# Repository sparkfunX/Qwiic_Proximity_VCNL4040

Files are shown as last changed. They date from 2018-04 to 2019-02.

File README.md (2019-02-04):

SparkFun VCNL4040 Proximity Sensor (Qwiic) - VCNL4040
===========================================================

SparkFun Proximity Sensor (Qwiic) - VCNL4040

[*SparkX Proximity Sensor (Qwiic) - VCNL4040 (SPX-14690)*](https://www.sparkfun.com/products/14690)

The VCNL4040 is a simple IR presence and ambient light sensor. This sensor is excellent for detecting if something has appeared in front of the sensor. We often see this type of sensor on automatic towel dispensers, automatic faucets, etc. You can detect objects qualitatively up to 20cm away. This means you can detect if something is there, and if it is closer or further away since the last reading, but it's difficult to say it is 7.2cm away. If you need quantitative distance readings (for example sensing that an object is 177mm away) check out the [SparkFun Time of Flight (ToF) sensors](https://www.sparkfun.com/categories/84) with mm accuracy.

SparkFun labored with love to create this code. Feel like supporting open source hardware? 
Buy a [breakout board](https://www.sparkfun.com/products/14690) from SparkFun!

Repository Contents
-------------------

* **/Documents** - Datasheets
* **/Hardware** - Eagle design files (.brd, .sch)

Library
--------------
* **[Arduino Library](https://github.com/sparkfun/SparkFun_VCNL4040_Arduino_Library)** - Library for reading distance and configuring the sensor

License Information
-------------------

This product is _**open source**_! 

If you have any questions or concerns on licensing, please contact techsupport@sparkfun.com.

Please use, reuse, and modify these files as you see fit. Please maintain attribution to SparkFun Electronics and release any derivative under the same license.

Distributed as-is; no warranty is given.

- Your friends at SparkFun.

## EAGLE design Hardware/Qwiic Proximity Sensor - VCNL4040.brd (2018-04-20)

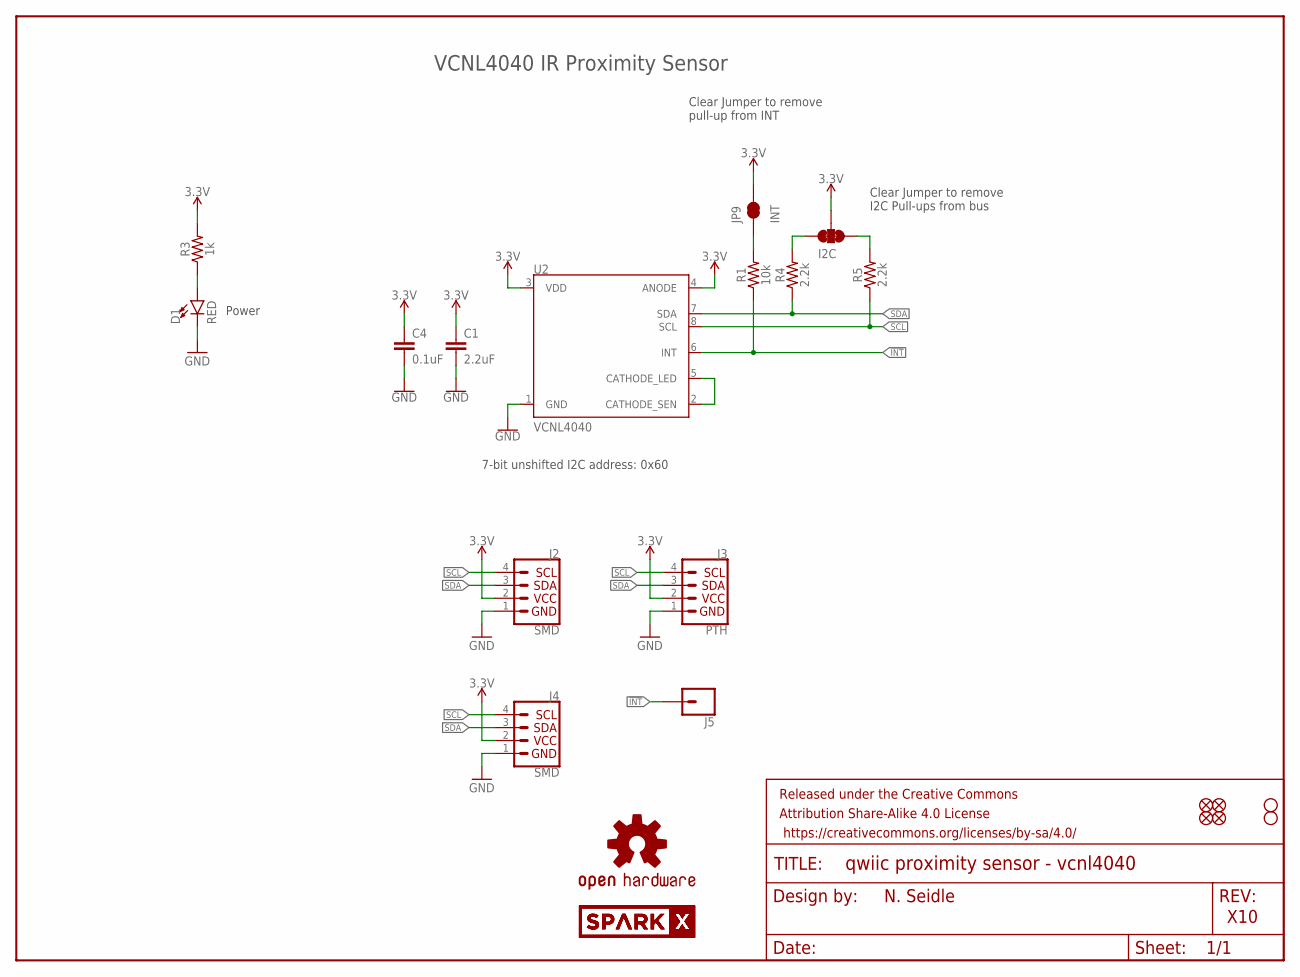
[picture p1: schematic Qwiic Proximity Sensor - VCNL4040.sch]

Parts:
C1: 2.2uF; 0603
C4: 0.1uF; 0603
D1: RED; LED-0603
FRAME1: FRAME-LETTER; CREATIVE_COMMONS
I2C: JUMPER-SMT_3_2-NC_TRACE_SILK; SMT-JUMPER_3_2-NC_TRACE_SILK
J2, J4: SMD; 1X04_1MM_RA
J3: PTH; 1X04_NO_SILK
J5: CONN_01PTH_NO_SILK_YES_STOP; 1X01_NO_SILK
JP1, JP2, JP5, JP6: FIDUCIALUFIDUCIAL; MICRO-FIDUCIAL
JP3, JP4: STAND-OFF
JP9: INT; PAD-JUMPER-2-NC_BY_TRACE_YES_SILK
LOGO1: OSHW-LOGOMINI; OSHW-LOGO-MINI
R1: 10k; 0603
R3: 1k; 0603
R4, R5: 2.2k; 0603
U2: VCNL4040
U$1, U$2: SPARKX-LOGO4; SPARKX-MEDIUM

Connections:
3.3V: C1.1, C4.1, I2C.2, J2.2 (VCC), J3.2 (VCC), J4.2 (VCC), JP9.2, R3.2, U2.3 (VDD), U2.4 (ANODE)
!INT: J5.1, R1.1, U2.6 (INT)
GND: C1.2, C4.2, D1.C, J2.1 (GND), J3.1 (GND), J4.1 (GND), U2.1 (GND)
unnamed: I2C.1, R5.2
unnamed: I2C.3, R4.2
unnamed: D1.A, R3.1
unnamed: JP9.1, R1.2
unnamed: U2.2 (CATHODE_SEN), U2.5 (CATHODE_LED)
SCL: J2.4 (SCL), J3.4 (SCL), J4.4 (SCL), R5.1, U2.8 (SCL)
SDA: J2.3 (SDA), J3.3 (SDA), J4.3 (SDA), R4.1, U2.7 (SDA)

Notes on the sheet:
N. Seidle
X10
7-bit unshifted I2C address: 0x60
Clear Jumper to remove I2C Pull-ups from bus
Clear Jumper to remove pull-up from INT
Power
VCNL4040 IR Proximity Sensor

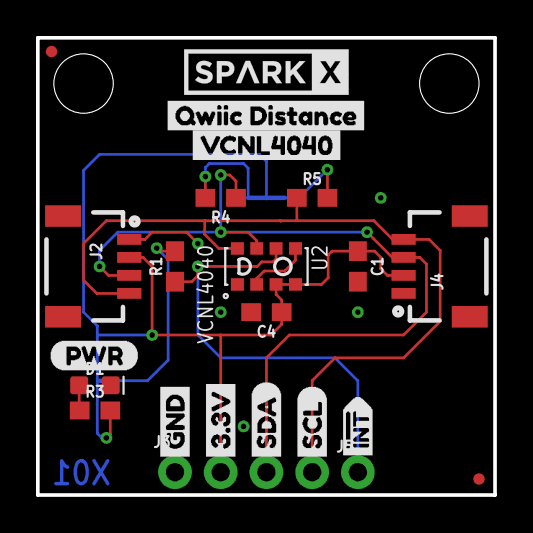
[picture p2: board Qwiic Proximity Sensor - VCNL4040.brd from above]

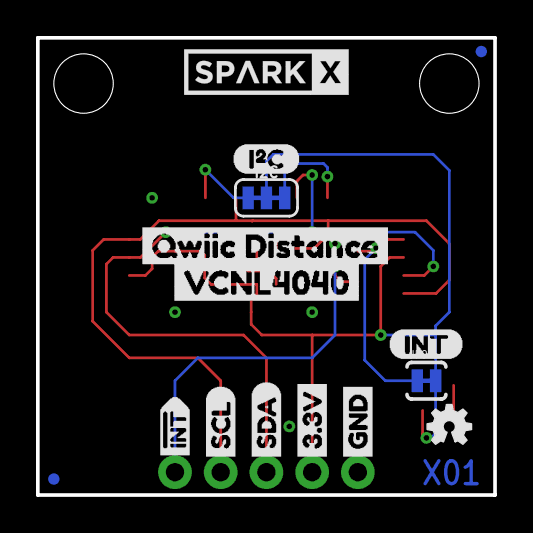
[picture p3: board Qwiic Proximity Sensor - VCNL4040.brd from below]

Board: 2 copper layers, 25.4 x 25.4 mm, 41 parts (15 on the bottom side), 10 nets.

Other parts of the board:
U$3, U$22: GND1
U$4, U$21: 3#3V2
U$5, U$27: SDA8
U$6, U$26: SCL9
U$7, U$25: #INT14
U$10: (PWR)
U$11: (I_SUPER2_C)
U$12: (INT)
U$13: VCNL40400
U$14: VCNL40401
U$15: QWIIC_DISTANCE7
U$19: QWIIC_DISTANCE9

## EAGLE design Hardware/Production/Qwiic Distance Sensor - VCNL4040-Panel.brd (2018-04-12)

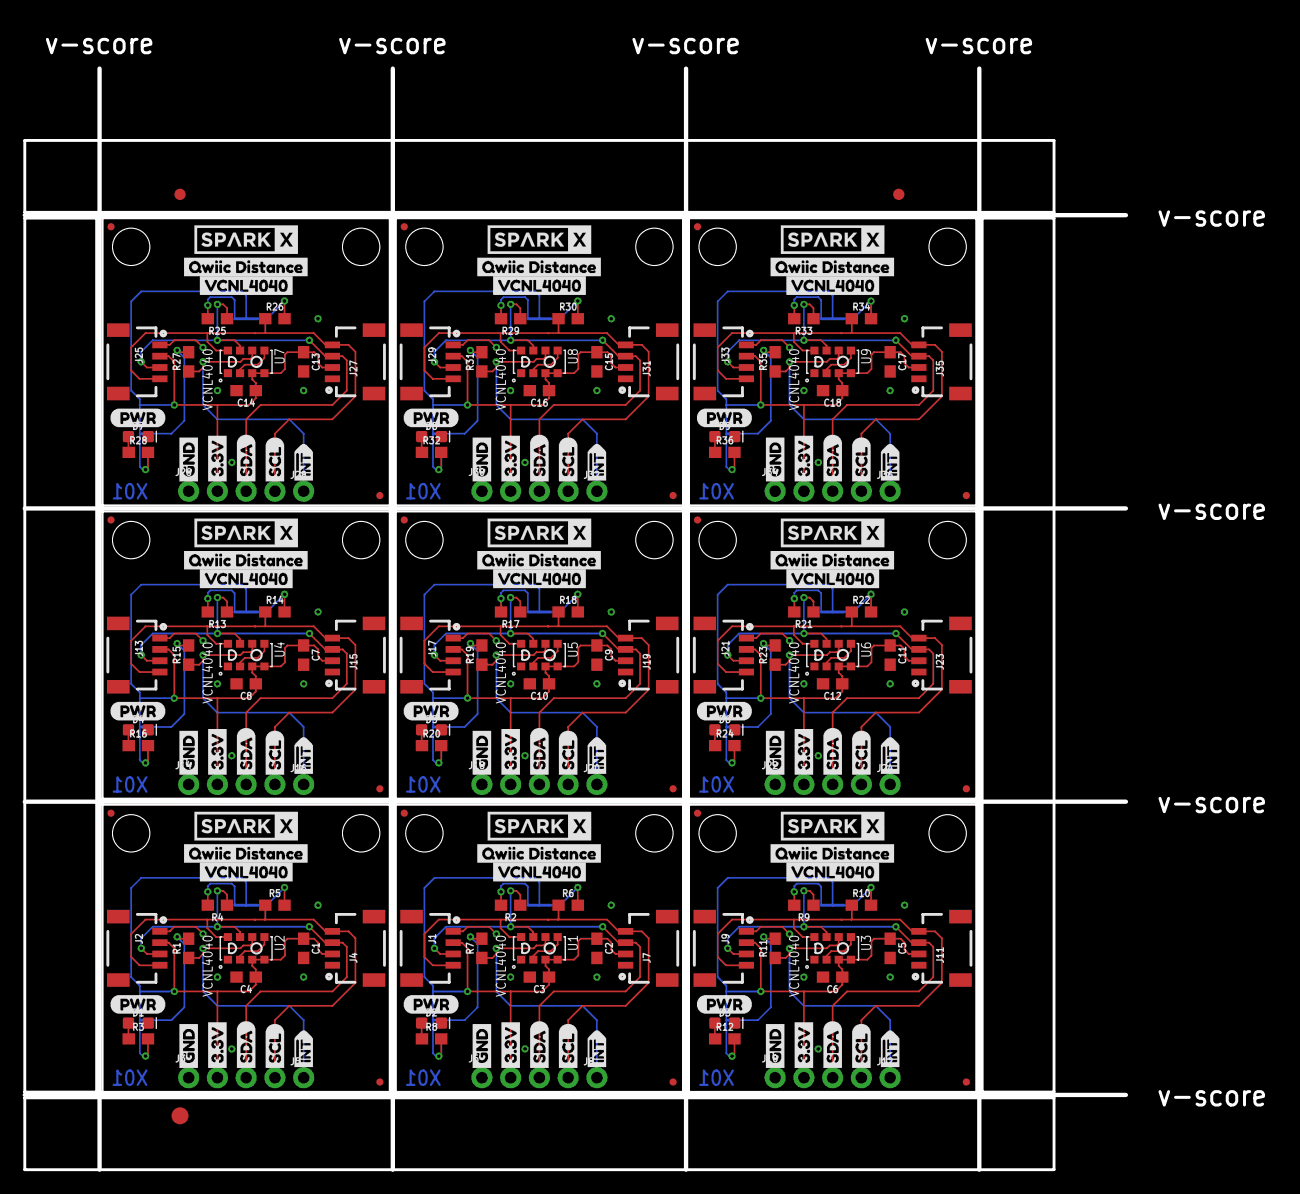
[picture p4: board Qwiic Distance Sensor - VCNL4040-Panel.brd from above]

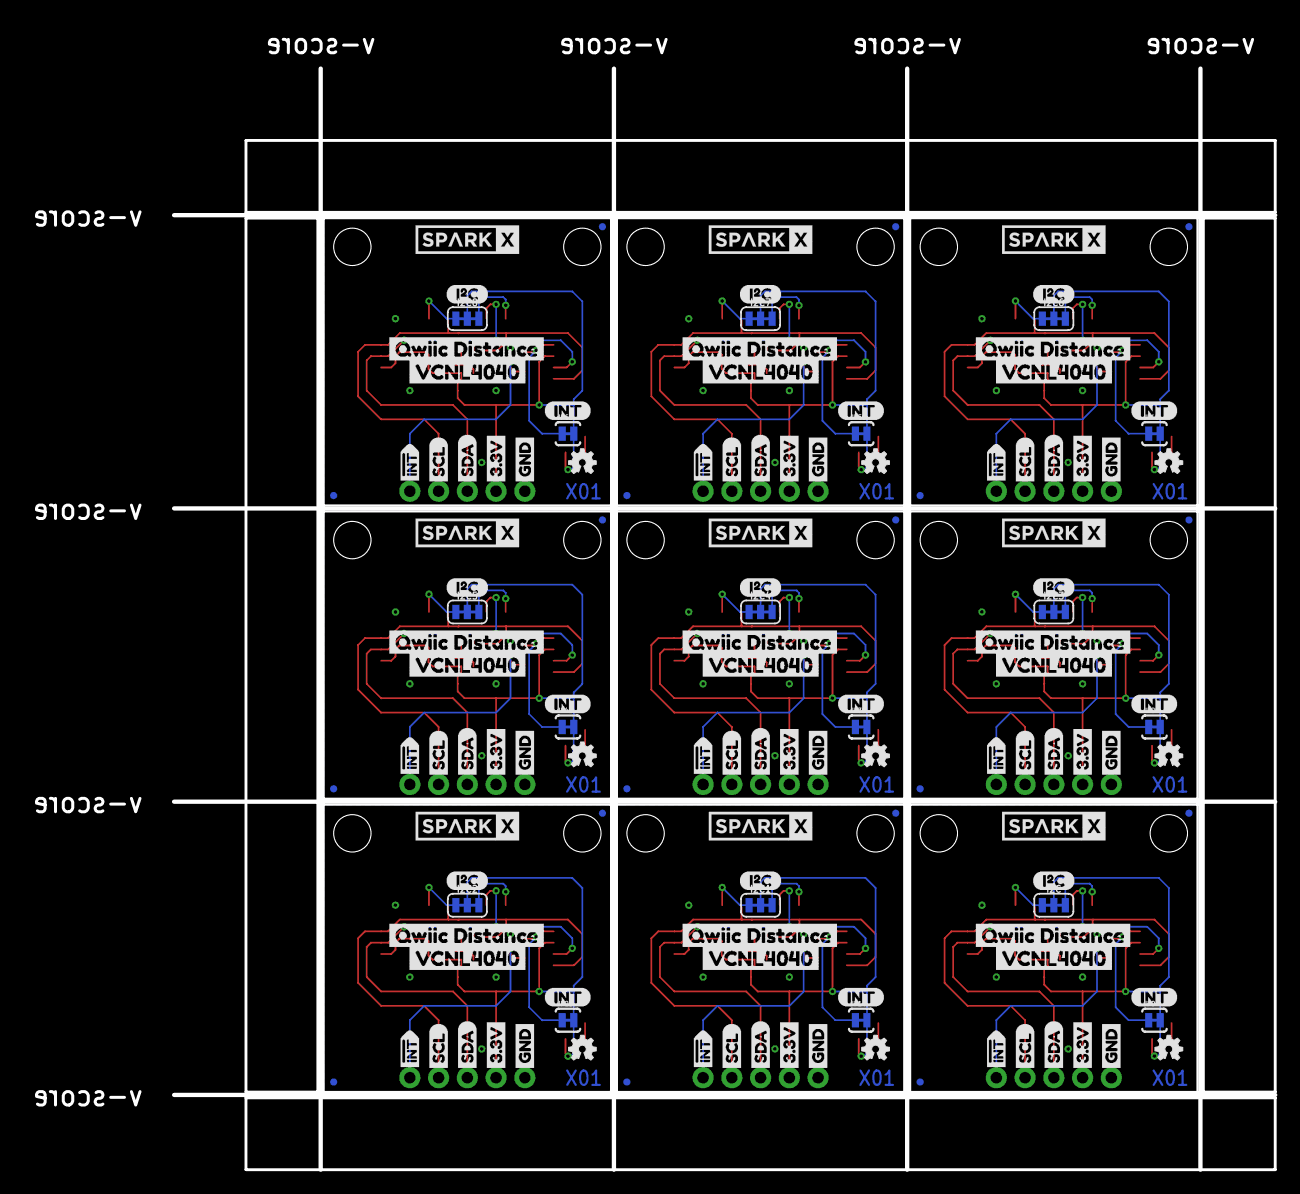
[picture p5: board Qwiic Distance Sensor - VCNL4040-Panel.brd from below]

Board: 2 copper layers, 97.3 x 97.3 mm, 363 parts (135 on the bottom side), 90 nets.

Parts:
C1, C2, C5, C7, C9, C11, C13, C15, C17: 2.2uF; 0603
C3, C4, C6, C8, C10, C12, C14, C16, C18: 0.1uF; 0603
D1, D2, D3, D4, D5, D6, D7, D8, D9: RED; LED-0603
E$1, E$2: FIDUCIAL-1X2
E$3: FIDUCIAL-1.5X3
I2C, I2C1, I2C2, I2C3, I2C4, I2C5, I2C6, I2C7, I2C8: SMT-JUMPER_3_2-NC_TRACE_SILK
J1, J2, J4, J7, J9, J11, J13, J15, J17, J19, J21, J23, J25, J27, J29, J31, J33, J35: SMD; 1X04_1MM_RA
J3, J6, J10, J14, J18, J22, J26, J30, J34: PTH; 1X04_NO_SILK
J5, J8, J12, J16, J20, J24, J28, J32, J36: 1X01_NO_SILK
JP1, JP2, JP5, JP6, JP10, JP11, JP12, JP13, JP17, JP18, JP19, JP20, JP24, JP25, JP26, JP27, JP31, JP32, JP33, JP34, JP38, JP39, JP40, JP41, JP45, JP46, JP47, JP48, JP52, JP53, JP54, JP55, JP59, JP60, JP61, JP62: FIDUCIALUFIDUCIAL; MICRO-FIDUCIAL
JP3, JP4, JP7, JP8, JP15, JP16, JP22, JP23, JP29, JP30, JP36, JP37, JP43, JP44, JP50, JP51, JP57, JP58: STAND-OFF
JP9, JP14, JP21, JP28, JP35, JP42, JP49, JP56, JP63: INT; PAD-JUMPER-2-NC_BY_TRACE_YES_SILK
LOGO1, LOGO2, LOGO3, LOGO4, LOGO5, LOGO6, LOGO7, LOGO8, LOGO9: OSHW-LOGOMINI; OSHW-LOGO-MINI
R1, R7, R11, R15, R19, R23, R27, R31, R35: 10k; 0603
R2, R4, R5, R6, R9, R10, R13, R14, R17, R18, R21, R22, R25, R26, R29, R30, R33, R34: 2.2k; 0603
R3, R8, R12, R16, R20, R24, R28, R32, R36: 1k; 0603
U1, U2, U3, U4, U5, U6, U7, U8, U9: VCNL4040
U$1, U$2, U$8, U$9, U$39, U$40, U$58, U$59, U$77, U$78, U$96, U$97, U$115, U$116, U$134, U$135, U$153, U$154: SPARKX-LOGO4; SPARKX-MEDIUM
U$3, U$20, U$22, U$29, U$44, U$48, U$63, U$67, U$82, U$86, U$101, U$105, U$120, U$124, U$139, U$143, U$158, U$162: GND1
U$4, U$18, U$21, U$30, U$43, U$49, U$62, U$68, U$81, U$87, U$100, U$106, U$119, U$125, U$138, U$144, U$157, U$163: 3#3V2
U$5, U$27, U$28, U$31, U$47, U$50, U$66, U$69, U$85, U$88, U$104, U$107, U$123, U$126, U$142, U$145, U$161, U$164: SDA8
U$6, U$24, U$26, U$32, U$46, U$51, U$65, U$70, U$84, U$89, U$103, U$108, U$122, U$127, U$141, U$146, U$160, U$165: SCL9
U$7, U$23, U$25, U$33, U$45, U$52, U$64, U$71, U$83, U$90, U$102, U$109, U$121, U$128, U$140, U$147, U$159, U$166: #INT14
U$10, U$34, U$53, U$72, U$91, U$110, U$129, U$148, U$167: (PWR)
U$11, U$35, U$54, U$73, U$92, U$111, U$130, U$149, U$168: (I_SUPER2_C)
U$12, U$36, U$55, U$74, U$93, U$112, U$131, U$150, U$169: (INT)
U$13, U$37, U$56, U$75, U$94, U$113, U$132, U$151, U$170: VCNL40400
U$14, U$38, U$57, U$76, U$95, U$114, U$133, U$152, U$171: VCNL40401
U$15, U$16, U$41, U$60, U$79, U$98, U$117, U$136, U$155: QWIIC_DISTANCE7
U$17, U$19, U$42, U$61, U$80, U$99, U$118, U$137, U$156: QWIIC_DISTANCE9

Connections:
3.3V: C1.1, C4.1, I2C.2, J2.2, J3.2, J4.2, JP9.2, R3.2, U2.3, U2.4
3.3V1: C2.1, C3.1, I2C1.2, J1.2, J6.2, J7.2, JP14.2, R8.2, U1.3, U1.4
3.3V2: C5.1, C6.1, I2C2.2, J9.2, J10.2, J11.2, JP21.2, R12.2, U3.3, U3.4
3.3V3: C7.1, C8.1, I2C3.2, J13.2, J14.2, J15.2, JP28.2, R16.2, U4.3, U4.4
3.3V4: C9.1, C10.1, I2C4.2, J17.2, J18.2, J19.2, JP35.2, R20.2, U5.3, U5.4
3.3V5: C11.1, C12.1, I2C5.2, J21.2, J22.2, J23.2, JP42.2, R24.2, U6.3, U6.4
3.3V6: C13.1, C14.1, I2C6.2, J25.2, J26.2, J27.2, JP49.2, R28.2, U7.3, U7.4
3.3V7: C15.1, C16.1, I2C7.2, J29.2, J30.2, J31.2, JP56.2, R32.2, U8.3, U8.4
3.3V8: C17.1, C18.1, I2C8.2, J33.2, J34.2, J35.2, JP63.2, R36.2, U9.3, U9.4
!INT: J5.1, R1.1, U2.6
!INT1: J8.1, R7.1, U1.6
!INT2: J12.1, R11.1, U3.6
!INT3: J16.1, R15.1, U4.6
!INT4: J20.1, R19.1, U5.6
!INT5: J24.1, R23.1, U6.6
!INT6: J28.1, R27.1, U7.6
!INT7: J32.1, R31.1, U8.6
!INT8: J36.1, R35.1, U9.6
GND: C1.2, C4.2, D1.C, J2.1, J3.1, J4.1, U2.1
GND1: C2.2, C3.2, D2.C, J1.1, J6.1, J7.1, U1.1
GND2: C5.2, C6.2, D3.C, J9.1, J10.1, J11.1, U3.1
GND3: C7.2, C8.2, D4.C, J13.1, J14.1, J15.1, U4.1
GND4: C9.2, C10.2, D5.C, J17.1, J18.1, J19.1, U5.1
GND5: C11.2, C12.2, D6.C, J21.1, J22.1, J23.1, U6.1
GND6: C13.2, C14.2, D7.C, J25.1, J26.1, J27.1, U7.1
GND7: C15.2, C16.2, D8.C, J29.1, J30.1, J31.1, U8.1
GND8: C17.2, C18.2, D9.C, J33.1, J34.1, J35.1, U9.1
unnamed: I2C.1, R5.2
unnamed: I2C.3, R4.2
unnamed: D1.A, R3.1
unnamed: JP9.1, R1.2
unnamed: I2C1.1, R6.2
unnamed: U2.2, U2.5
unnamed: I2C1.3, R2.2
unnamed: JP14.1, R7.2
unnamed: D2.A, R8.1
unnamed: U1.2, U1.5
unnamed: I2C2.1, R10.2
unnamed: I2C2.3, R9.2
unnamed: JP21.1, R11.2
unnamed: D3.A, R12.1
unnamed: U3.2, U3.5
unnamed: I2C3.1, R14.2
unnamed: I2C3.3, R13.2
unnamed: JP28.1, R15.2
unnamed: D4.A, R16.1
unnamed: U4.2, U4.5
unnamed: I2C4.1, R18.2
unnamed: I2C4.3, R17.2
unnamed: JP35.1, R19.2
unnamed: D5.A, R20.1
unnamed: U5.2, U5.5
unnamed: I2C5.1, R22.2
unnamed: I2C5.3, R21.2
unnamed: JP42.1, R23.2
unnamed: D6.A, R24.1
unnamed: U6.2, U6.5
unnamed: I2C6.1, R26.2
unnamed: I2C6.3, R25.2
unnamed: JP49.1, R27.2
unnamed: D7.A, R28.1
unnamed: U7.2, U7.5
unnamed: I2C7.1, R30.2
unnamed: I2C7.3, R29.2
unnamed: JP56.1, R31.2
unnamed: D8.A, R32.1
unnamed: U8.2, U8.5
unnamed: I2C8.1, R34.2
unnamed: I2C8.3, R33.2
unnamed: JP63.1, R35.2
unnamed: D9.A, R36.1
unnamed: U9.2, U9.5
SCL: J2.4, J3.4, J4.4, R5.1, U2.8
SCL1: J1.4, J6.4, J7.4, R6.1, U1.8
SCL2: J9.4, J10.4, J11.4, R10.1, U3.8
SCL3: J13.4, J14.4, J15.4, R14.1, U4.8
SCL4: J17.4, J18.4, J19.4, R18.1, U5.8
SCL5: J21.4, J22.4, J23.4, R22.1, U6.8
SCL6: J25.4, J26.4, J27.4, R26.1, U7.8
SCL7: J29.4, J30.4, J31.4, R30.1, U8.8
SCL8: J33.4, J34.4, J35.4, R34.1, U9.8
SDA: J2.3, J3.3, J4.3, R4.1, U2.7
SDA1: J1.3, J6.3, J7.3, R2.1, U1.7
SDA2: J9.3, J10.3, J11.3, R9.1, U3.7
SDA3: J13.3, J14.3, J15.3, R13.1, U4.7
SDA4: J17.3, J18.3, J19.3, R17.1, U5.7
SDA5: J21.3, J22.3, J23.3, R21.1, U6.7
SDA6: J25.3, J26.3, J27.3, R25.1, U7.7
SDA7: J29.3, J30.3, J31.3, R29.1, U8.7
SDA8: J33.3, J34.3, J35.3, R33.1, U9.7

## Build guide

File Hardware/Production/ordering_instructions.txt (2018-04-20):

panel size, 91x91mm
PCB thickness, 1.6mm
number of layers, 2
soldermask color, Black
silkscreen color, White
oz copper, 1oz
finish, HASL lead free
stencils, top+bottom
pcs per panel, 9

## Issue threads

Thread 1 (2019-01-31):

Library link update

santaimpersonator, 2019-01-31:
It looks like the library linked in the README.md is for the MS5637 Barometric Pressure. I think it needs to point to here: [https://github.com/sparkfun/SparkFun_VCNL4040_Arduino_Library](https://github.com/sparkfun/SparkFun_VCNL4040_Arduino_Library)

nseidle, 2019-02-04:
Indeed! Thanks! Should be fixed now.

Closed 2019-02-04.

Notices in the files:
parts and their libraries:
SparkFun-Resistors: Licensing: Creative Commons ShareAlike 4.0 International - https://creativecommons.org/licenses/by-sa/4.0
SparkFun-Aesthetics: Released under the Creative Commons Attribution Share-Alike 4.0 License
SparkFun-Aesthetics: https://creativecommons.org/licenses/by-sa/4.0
